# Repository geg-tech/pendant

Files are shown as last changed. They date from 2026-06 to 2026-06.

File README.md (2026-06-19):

# pendant
my #pendant submission for hack club! based off the arcane potion from defend the statue np <br/>
> "wtf is defend the statue" you may ask <br/>
> its a roblox game! its really fun! play it! play it! play it! [now!](https://www.roblox.com/games/6911596531/Defend-the-Statue)
> i have like 160 hours in ts

this keychain lights up in rgb colors and changes colors depending if you shake it or not, powered all by a seeed esp32! <br/>

## schematic
 <br/>
> enjoy dumbfounded soup <br/>

## pcb
 <br/>
 <br/>
 <br/>

## cad n case n stuff
 <br/>
 <br/>
 <br/>
 <br/>

## bom
find it [here](https://github.com/geg-tech/pendant/blob/main/pendant%20BOM%20-%20Sheet1.csv)! (or just go to the bom shaped .csv file in this repo right above ya)

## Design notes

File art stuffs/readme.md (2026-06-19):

# woah
all of the assets n thingies i used to make this! <br/>

## inspiration/links
wiki page for the item i recreated: [https://dtsnp.miraheze.org/wiki/Class_Potions#tabber-Arcane_Potion](https://dtsnp.miraheze.org/wiki/Class_Potions#tabber-Arcane_Potion)
> ^ this link might change in the future (the miraheze is a wip!) <br/>

game this is based off of: [https://www.roblox.com/games/6911596531/Defend-the-Statue](https://www.roblox.com/games/6911596531/Defend-the-Statue) <br/>
<br/>
 <br/>
<br/>
 <br/>

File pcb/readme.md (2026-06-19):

# pcb stuff
find the source files n stuff here + production <br/>
> its a 2 for 1 deal! <br/>

 <br/>
 <br/>

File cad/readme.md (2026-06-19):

# yeah welcome to the cad n case zone

what else am i supposed to put here <br/>
idk <br/>

 <br/>
> pcb is supposed to be purple too but kicad exported the soldermask as a bunch of uncolorable surfaces lol

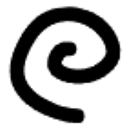
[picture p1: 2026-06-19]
art stuffs/swirl 2.png

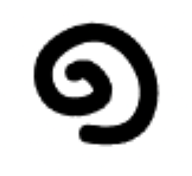
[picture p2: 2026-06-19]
art stuffs/swirl.png

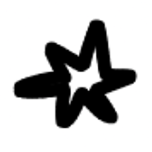
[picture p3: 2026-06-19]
art stuffs/boom.png

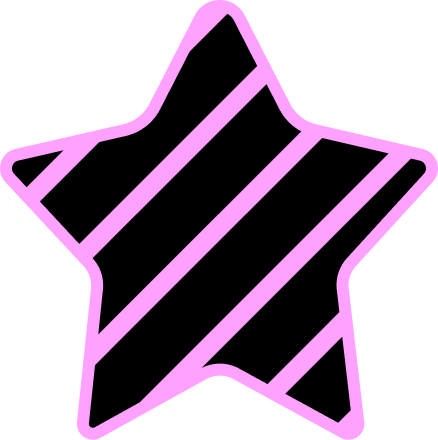
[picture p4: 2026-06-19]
art stuffs/filling star.png

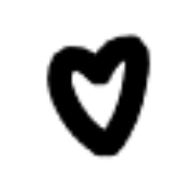
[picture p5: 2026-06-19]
art stuffs/heart.png

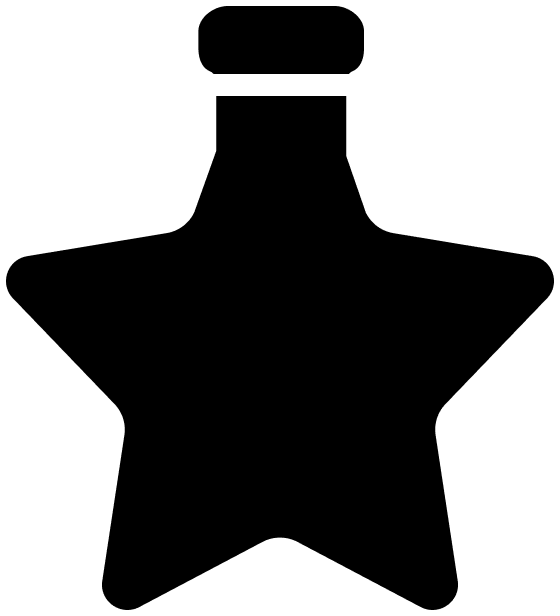
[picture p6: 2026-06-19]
art stuffs/outline.png

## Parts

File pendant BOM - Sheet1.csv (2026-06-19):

Name | Price | Purpose | Link
Seeed Studio XIAO ESP32-S3 | $4.60 | microcontroller | https://www.aliexpress.us/item/3256806801590776.html?curPageLogUid=GbnsKMYMMvNn
SK6812 Mini E | $2.42 | RGB LEDs that glow :D | https://www.aliexpress.us/item/3256805007401420.html?mp=1
MPU6050 | $2.88 (Already Owned) | gyroscope/accelerometer that senses motion/tilt | https://www.aliexpress.us/item/3256812014348809.html?curPageLogUid=7mJYeUUHuUoy
Slide Switch | $2.06 (Already Owned) | serves as a toggle for power | https://www.aliexpress.us/item/3256806975868130.html?curPageLogUid=15Y382B671XB
PCB | $5.30 | wires stuff together | JLCPCB
3.7V Battery | $5.44 | powers the thingy | https://www.aliexpress.us/item/3256808031709894.html?curPageLogUid=JW3njS3ESXuJ
3D printed case | $0 | holds the pcb in place and battery, look cool | printing myself
 | Subtotal: | $22.70
 | Actual subtotal (taking away items already owned): | $17.76
 | Actual Total (Shipping + tax): | $31.50

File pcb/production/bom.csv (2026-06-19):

Designator | Footprint | Quantity | Value | LCSC Part #
A1 | PinHeader_1x10_P2.54mm_Vertical | 1 | ~
D1, D10, D11, D12, D13, D14, D18, D2, D3, D4, D5, D6, D7, D9 | LED_SK6812MINI-E_3.2x2.8mm_P1.5mm_ReverseMount | 14 | SK6812MINI-E
SW1 | slideswitch | 1 | SW_SPDT
TP1 | TestPoint_Pad_D2.0mm | 1 | GND test Point
TP2 | TestPoint_Pad_D2.0mm | 1 | BAT Test Point
U1 | XIAO-ESP32S3-SMD | 1 | XIAO-ESP32-S3-SMD

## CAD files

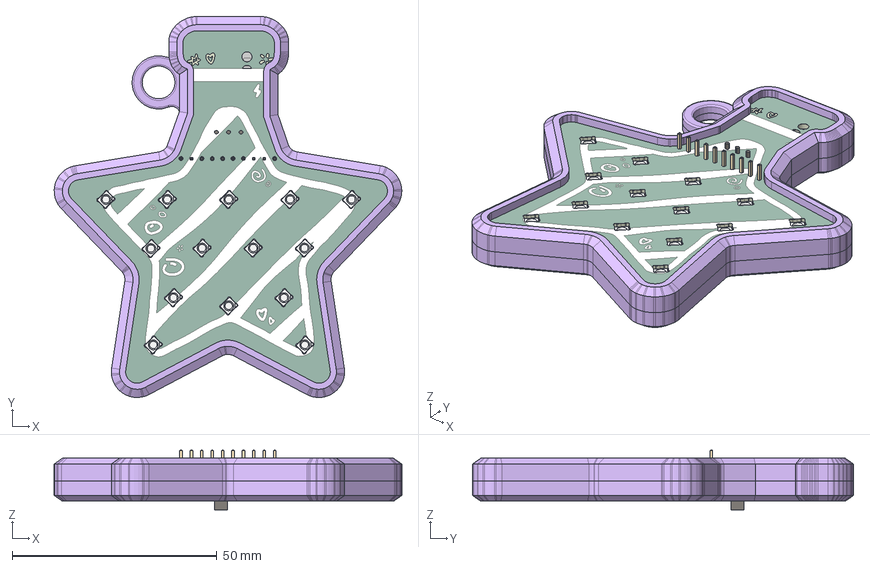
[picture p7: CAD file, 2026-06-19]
cad/pendant-assembly.step
84.9 x 93.1 x 14.6 mm
Pin1 x 14
Pin2 x 14
Pin3 x 14
Pin4 x 14
PinHeader_1x10_P2.54mm_Vertical
XIAO-ESP32S3 v2
pendant_silkscreen
pendant_silkscreen_1
pendant_soldermask
pendant_soldermask_1
pendant_PCB
mpu standin
bottom half
top half

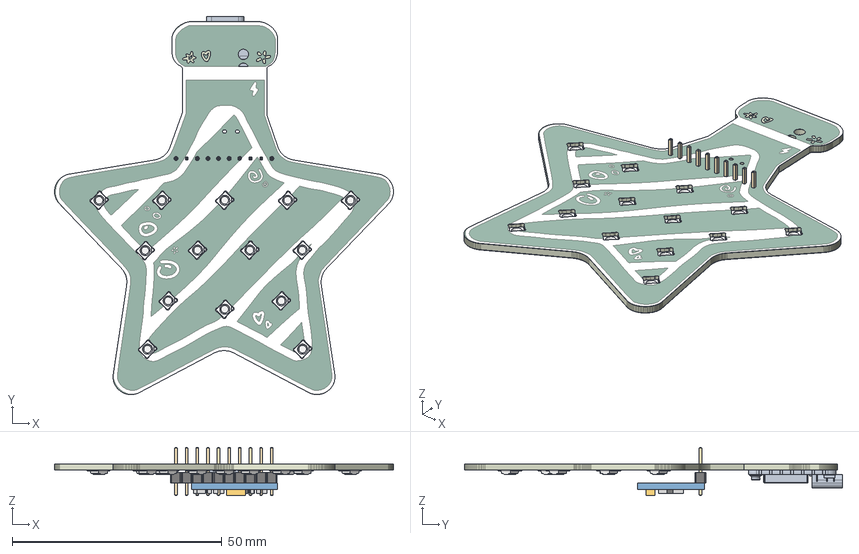
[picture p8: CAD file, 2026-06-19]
pcb/pendantbytfr.step
80.9 x 90.3 x 11.5 mm
Pin1 x 14
Pin2 x 14
Pin3 x 14
Pin4 x 14
PinHeader_1x10_P2.54mm_Vertical
pcb
XIAO-ESP32S3 v2
pendant_silkscreen x 2
pendant_soldermask x 2
pendant_PCB

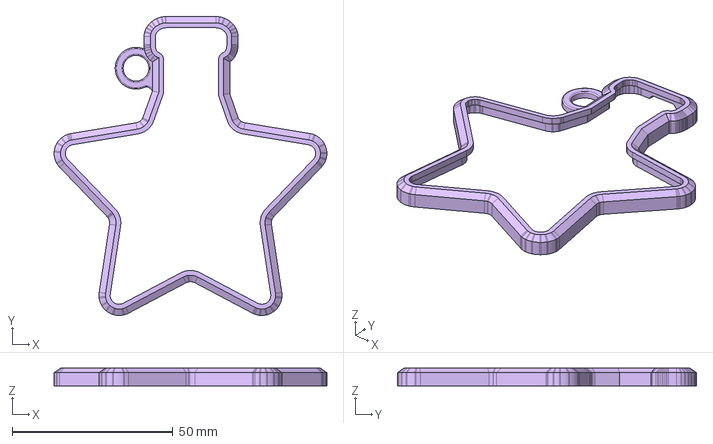
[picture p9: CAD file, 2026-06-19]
cad/top half.step
84.9 x 93.1 x 5.50 mm

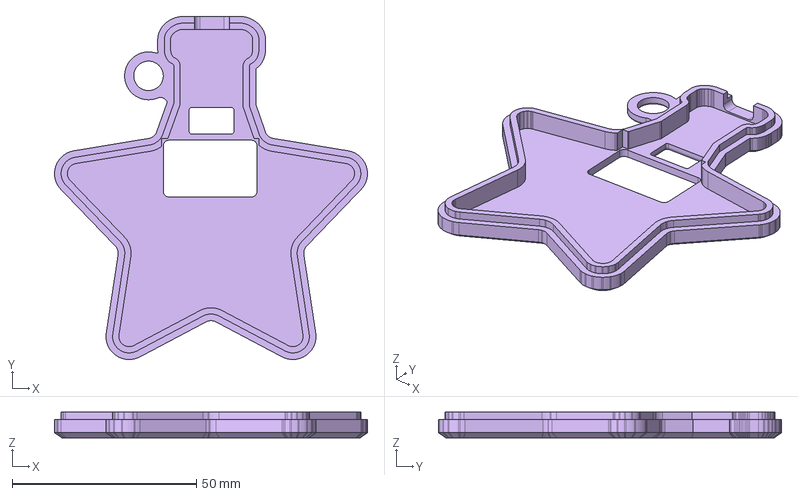
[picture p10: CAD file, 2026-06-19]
cad/bottom half.step
84.9 x 93.1 x 7.00 mm

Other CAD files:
cad/pendant-assembly.f3z

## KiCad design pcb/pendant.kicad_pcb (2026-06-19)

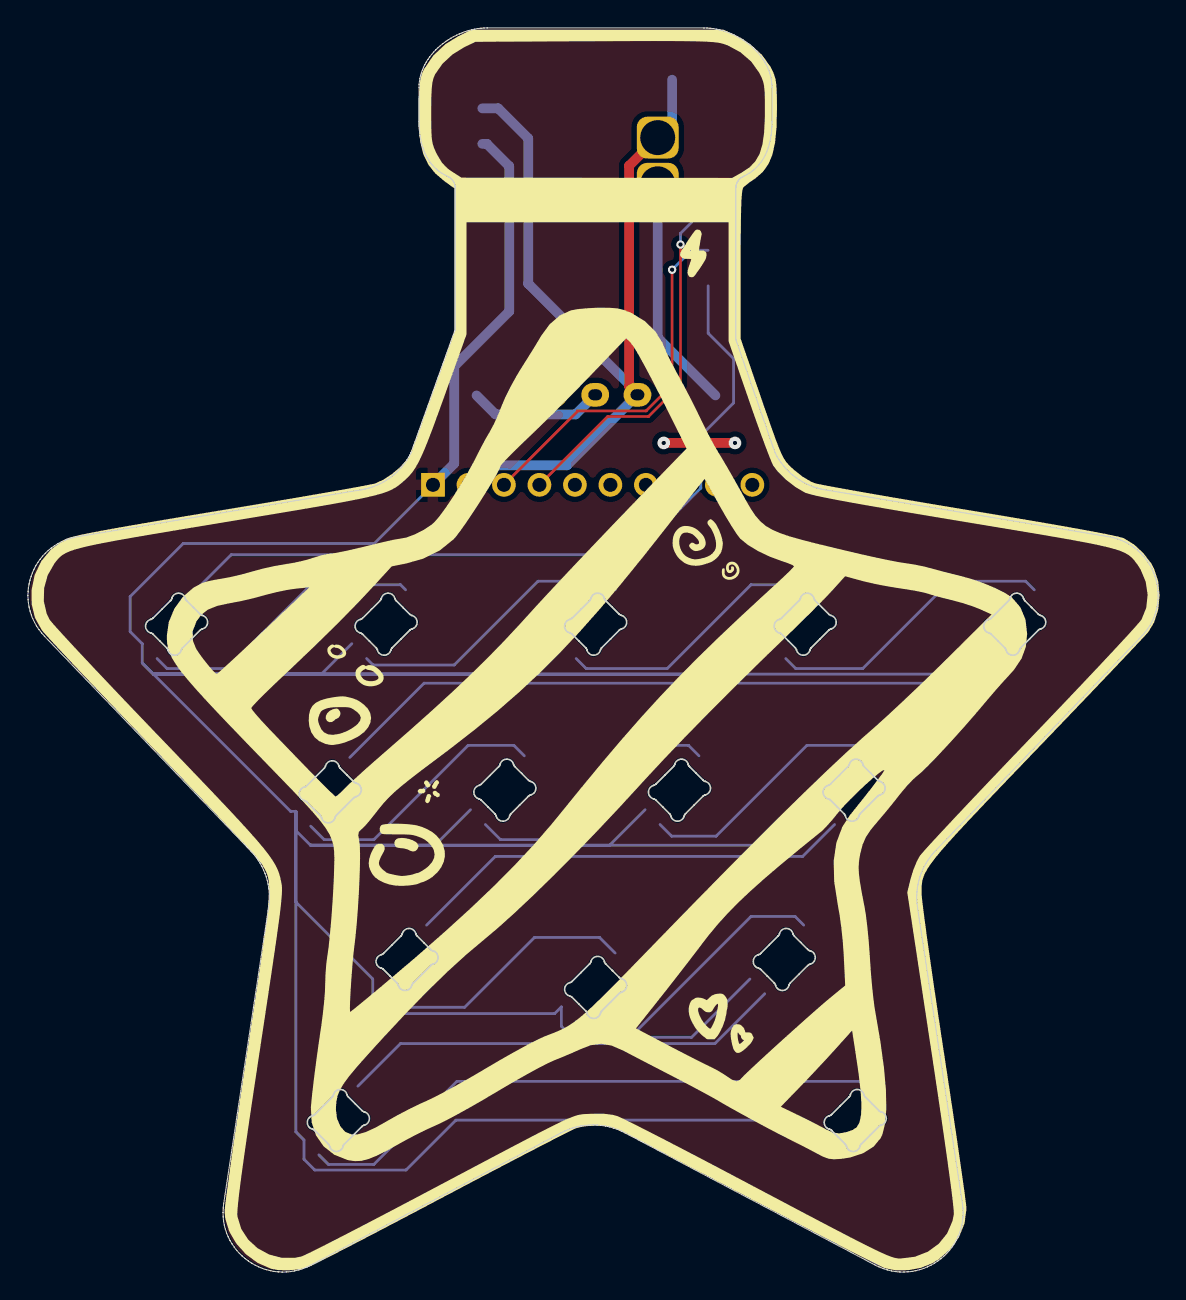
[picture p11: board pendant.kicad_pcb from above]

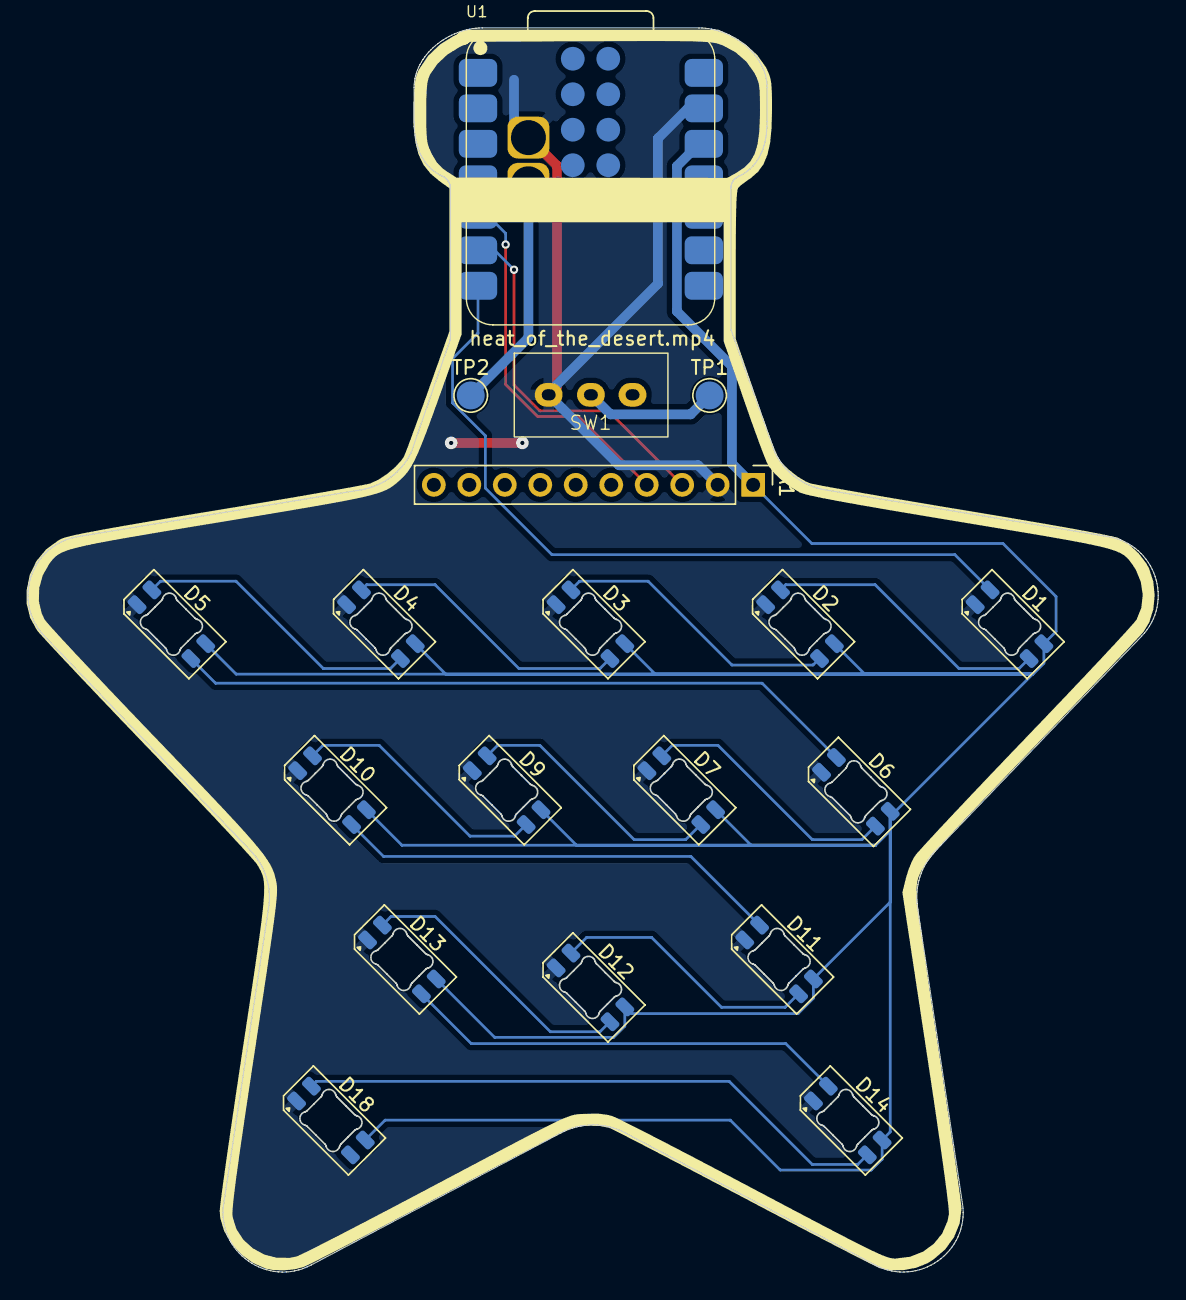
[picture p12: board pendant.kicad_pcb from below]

Board: 2 copper layers, 80.9 x 89.1 mm, 19 parts (19 on the bottom side), 20 nets.

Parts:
A1: PinHeader_1x10_P2.54mm_Vertical
D1, D2, D3, D4, D5, D6, D7, D9, D10, D11, D12, D13, D14, D18: SK6812MINI-E; LED_SK6812MINI-E_3.2x2.8mm_P1.5mm_ReverseMount
SW1: SW_SPDT; slideswitch
TP1: GND test Point; TestPoint_Pad_D2.0mm
TP2: BAT Test Point; TestPoint_Pad_D2.0mm
U1: XIAO-ESP32-S3-SMD; XIAO-ESP32S3-SMD

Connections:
+3V3: A1.1, D1.3 (VDD), D2.3 (VDD), D3.3 (VDD), D4.3 (VDD), D5.3 (VDD), D6.3 (VDD), D7.3 (VDD), D9.3 (VDD), D10.3 (VDD), D11.3 (VDD), D12.3 (VDD), D13.3 (VDD), D14.3 (VDD), D18.3 (VDD), U1.12 (3V3)
GND: A1.2, D1.1 (VSS), D2.1 (VSS), D3.1 (VSS), D4.1 (VSS), D5.1 (VSS), D6.1 (VSS), D7.1 (VSS), D9.1 (VSS), D10.1 (VSS), D11.1 (VSS), D12.1 (VSS), D13.1 (VSS), D14.1 (VSS), D18.1 (VSS), SW1.1 (A), U1.13 (GND), U1.16 (GND)
LED: D1.2 (DIN), U1.7 (GPIO43_A6_D6_TX)
unnamed: D1.4 (DOUT), D2.2 (DIN)
unnamed: D2.4 (DOUT), D3.2 (DIN)
unnamed: D3.4 (DOUT), D4.2 (DIN)
unnamed: D4.4 (DOUT), D5.2 (DIN)
unnamed: D5.4 (DOUT), D6.2 (DIN)
unnamed: D6.4 (DOUT), D7.2 (DIN)
unnamed: D7.4 (DOUT), D9.2 (DIN)
unnamed: D9.4 (DOUT), D10.2 (DIN)
unnamed: D10.4 (DOUT), D11.2 (DIN)
unnamed: D11.4 (DOUT), D12.2 (DIN)
unnamed: D12.4 (DOUT), D13.2 (DIN)
unnamed: D13.4 (DOUT), D14.2 (DIN)
unnamed: D14.4 (DOUT), D18.2 (DIN)
unnamed: SW1.1 (A), TP1.1 (1_1)
SCL: A1.3, U1.6 (GPIO6_A5_D5_SCL)
SDA: A1.4, U1.5 (GPIO5_A4_D4_SDA)
VBAT: TP2.1 (1_1), U1.15 (BAT)

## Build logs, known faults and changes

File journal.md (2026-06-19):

# la journale
>  17 38. ay. <br/>

this is the journal for my pendant submission! projects are due tomorrow so dev logs are gonna b pretty packed <br/>
* my submission is based on the [Arcane Potion](https://official-defend-the-statue.fandom.com/wiki/Class_Potions#Arcane_Potion) from [Defend The Statue: Nostalgic Proctors](https://www.roblox.com/games/6911596531/Defend-the-Statue), a roblox game i have way too much hours in lmao

### started: 6/17/26
### finished design: 6/18/26
### total hours (as of submission): ~8.6 hours

## 6/17/26 - comin up with ideas, drawing outlines
today i came up with some ideas for pendant <br/>
there's not that much criteria for pendant other than making it look pretty and being under 4 inches, so i started comin up with some ideas: <br/>
 <br/>
in the end i decided to do the fluid simulation idea with the arcane potion <br/>
* i feel like doing a fluid simulation with a more unusual shape like the star would be interesting + defend the statue was and is still now one of my fav games on roblox <br/>
* i also wanna experiment with different pcb colors other than my usual black and white silkscreen

after getting my idea sorted, i started work on my outline
* i chose figma to do this since ion really know any other vector drawing software other than like illustrator (in which my school booted my license) <br/>
 <br/>
the corners of the star are supposed to be sharper tbh but im planning to make the case for it wrap and sandwich the pcb around it so

### hours spent: 0.8 hours

## 6/18/26 (part 1) - coming up with general layout, schematic work
i should've came up with my layout before making my layout but whatever <br/>
anyways back to the excalidraw mines <br/>
 <br/>
thankfully i have a bunch of mpu6050 sensors from a project i planned to do but never did so i dont have to order those <br/>
after that, i went onto kicad to make my schematic <br/>

* i initially wanted to recreate an led matrix for my pendant, but after digging around and finding the [adafruit schematic for their neopixel matrix](https://github.com/adafruit/Adafruit-NeoPixel-8x8-Matrix/blob/master/Adafruit_NeoMatrix_8x8%20v2.sch), i realized that its quite literally just the same type of config i've been using for my rgb lights but with extra capacitors and a resistor lmao <br/>
* i also tossed in a slide power switch so that i dont burn all of my battery when i permanently solder my board together. i initially thought i was gonna have to buy new slide switches, but i found one lying around in my stash of electronic parts
* i wired up the accelerometer according to this [handy article](https://lastminuteengineers.com/mpu6050-accel-gyro-arduino-tutorial/#mpu6050-module-pinout) by last minute engineers (idk what else to say)

### hours spent: 1.9 hours

## 6/18/26 (part 2) - pcb design!!!
ok its slightly too big :peefest: <br/>
for the most part i followed the usual footprints, only having to make a custom footprint for my slide switch with some calipers since the pins on the switch are just a tiny bit too big for the usual pin header connector footprints <br/>
however when importing my svg into kicad, i measured the height of the board to be around 110mm, or just bigger than 4 inches <br/>
 <br/>
which meant: <br/>
### REDESIGN TIME!!!!!!!!!!!!
> (and by redesign i just lowered the neck of the potion and made it a tinge wider so i dont have to scale it as much
 <br/>
yeah sure its not game accurate anymore but womp womp id rather have the cool ass lanyard and keychain <br/>

after getting that sorted (its now 3.5 inches ish), i placed down my components
* i took inspiration from the split keeb tutorial on blueprint, specifically copying the xiao footprint in their repo for mine since the footprint that came with mine didn't have the holes to solder the battery pads
* after that, i arranged my leds in the star pattern of my outline. i angled the leds to 45 degrees for aesthetics, making sure to space them out roughly evenly <br/>
 <br/>
* the front part is what will be shown in the final product, so i'll have most of my decorative and pretty drawings on there, while the back is gonna be covered up (so memes n shitposts)
* its also why most of my components are on the back <br/>
after getting my layout, i started routing <br/>
* again, i used the track widths found in the split keeb tutorial to guide my routing for the battery/power system since its pretty much identical other than the microcontroller
* this was also where i found out you could change the board requirements in kicad to dodge drc errors (i had like 56 of them due to the led footprints lol) <br/>


## hours spent: 2-ish hours

## 6/18/26 (part 3) - ART!!!!!!!!!!!!!!!!
now that i had the annoyin circuit stuff out of the way, i could focus on making the pcb look pretty :D <br/>
* i started off with the outline i had in figma, creating an inner outline to make a simple border around the pcb
* after that, i recreated the neon purple inside of the potion by creating a rounded star. to replicate the "color", i used a diagonal line shading thing which was made by using the pattern fill option with a square with diagonal lines in it <br/>
 <br/>
* the filling looked a little *too* clean and straight in a sense, so i went back and purposefuly made the filling look more wavy and handrawn, which i feel improved the vibe of the pcb a ton
* after that, i started work on smaller decor, starting off my drawing some small doodles in kleki and importing them into figma so i could resize them for kicad <br/>
 <br/>
i aimed for magical-themed doodles (waves, lightning, swirls, etc.) and tossed them into my pcb <br/>
> this was also where i found out that kleki had a smoothening option! made drawing on trackpad 10000000 times easier :3 <br/>

 <br/>
the 3d models for the components were fairly easy to get tbh. the only issue i had was not finding the specific MPU6050 i had which had 10 pins, so i decided to just settle on an 8 pin model and call it there lol <br/>
 <br/>

## hours spent: 1.4 hours

## 6/18/26 (part 4) - cad and finishing!!!
woah mama its like 23 minutes until the due date (i'll make this quick)<br/>
after i got my pcb done and decorated, i dragged fusion out of its dusty bed and worked on the cad <br/>
* my plan for the case was fairly simple: make an enclosure encasing the back but exposing the front of the pcb
* i considered making a cover for the front to diffuse the light, but im highkey running out of time lmao

it was a bit of a pain to do projections and outlines of the pcb in cad due to the custom outline in figma translating into kicad, then fusion (and thus resulting in an edge that had like a million arcs and segments), but we lowk got there <br/>
 <br/>
in an attempt to stay true to the source material, i made the case a light lavender-ish purple, as well as making a slightly thicker hole to hook onto the lanyard <br/>
 <br/>
i designed my case so that the halves should press fit into each other securely with the lanyard providing support through the ring, but a light amount of glue also works ig (yuck glue) <br/>
 <br/>

after that, i went to the repo and uploaded all of my stuff. for the firmware, i'm using the code from [this post from digikey](https://www.digikey.com/en/maker/projects/esp32-fluid-simulation-on-16x16-led-matrix/9c5a42f7ecfd43d9bc7689b2e9a5113f) about their fluid simulation, through slightly tweaked to not leave in the color select button and to use my pinout.
* yeah its kinda cheaty, but at the same time most of the components are similiar + wip firmware

hours spent: 2.5-ish hours

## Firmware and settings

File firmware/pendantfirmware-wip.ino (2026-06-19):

 // colors:   0 = Red, 32 = Orange, 64 = Yellow, 96 = Green, 128 = Aqua, 160 = Blue, 192 = Purple, 224 = Pink


#include <FastLED.h>
#include <Wire.h>
#include <MPU6050.h>

// Pin definitions
#define LED_PIN     5
#define SDA_PIN     21
#define SCL_PIN     22

#define NUM_LEDS    256
#define MATRIX_WIDTH 16
#define MATRIX_HEIGHT 16
#define FLUID_PARTICLES 64  //80/64
#define BRIGHTNESS  30
#define NUM_COLORS  3   // Number of color options

// Structures
struct Vector2D {
    float x;
    float y;
};

struct Particle {
    Vector2D position;
    Vector2D velocity;
};

// Global variables
CRGB leds[NUM_LEDS];
MPU6050 mpu;
Particle particles[FLUID_PARTICLES];
Vector2D acceleration = {0, 0};

// Color switching variables
uint8_t currentColorIndex = 0;
unsigned long lastDebounceTime = 0;
const unsigned long debounceDelay = 200;

// Define the colors (you can change these hue values)
const uint8_t COLORS[NUM_COLORS] = {
    160,  // Blue
    0,    // Red
    96    // Green
};

// Mutex for synchronization
portMUX_TYPE dataMux = portMUX_INITIALIZER_UNLOCKED;

// Constants for physics
const float GRAVITY = 0.08f;  //0.3f /098f
const float DAMPING = 0.92f;   //0.99f /0.9f
const float MAX_VELOCITY = 0.6f; //0.6f /2.9f

// Function prototypes
void initMPU6050();
void initLEDs();
void initParticles();
void updateParticles();
void drawParticles();
void MPUTask(void *parameter);
void LEDTask(void *parameter);
void checkButton();

// Function to convert x,y coordinates to LED index
int xy(int x, int y) {
    x = constrain(x, 0, MATRIX_WIDTH - 1);
    y = constrain(y, 0, MATRIX_HEIGHT - 1);
    return (y & 1) ? (y * MATRIX_WIDTH + (MATRIX_WIDTH - 1 - x)) : (y * MATRIX_WIDTH + x);
}

void checkButton() {
    static bool lastButtonState = HIGH;
    bool buttonState = digitalRead(BUTTON_PIN);

    if (buttonState == LOW && lastButtonState == HIGH) {  // Button pressed
        if ((millis() - lastDebounceTime) > debounceDelay) {
            currentColorIndex = (currentColorIndex + 1) % NUM_COLORS;
            lastDebounceTime = millis();
        }
    }
    lastButtonState = buttonState;
}

void drawParticles() {
    FastLED.clear();
    
    bool occupied[MATRIX_WIDTH][MATRIX_HEIGHT] = {{false}};
    
    struct ParticleIndex {
        int index;
        float position;
    };
    
    ParticleIndex sortedParticles[FLUID_PARTICLES];
    for (int i = 0; i < FLUID_PARTICLES; i++) {
        sortedParticles[i].index = i;
        sortedParticles[i].position = particles[i].position.y * MATRIX_WIDTH + particles[i].position.x;
    }
    
    for (int i = 0; i < FLUID_PARTICLES - 1; i++) {
        for (int j = 0; j < FLUID_PARTICLES - i - 1; j++) {
            if (sortedParticles[j].position > sortedParticles[j + 1].position) {
                ParticleIndex temp = sortedParticles[j];
                sortedParticles[j] = sortedParticles[j + 1];
                sortedParticles[j + 1] = temp;
            }
        }
    }

    for (int i = 0; i < FLUID_PARTICLES; i++) {
        int particleIndex = sortedParticles[i].index;
        int x = round(particles[particleIndex].position.x);
        int y = round(particles[particleIndex].position.y);
        
        x = constrain(x, 0, MATRIX_WIDTH - 1);
        y = constrain(y, 0, MATRIX_HEIGHT - 1);
        
        if (!occupied[x][y]) {
            int index = xy(x, y);
            if (index >= 0 && index < NUM_LEDS) {
                float speed = sqrt(
                    particles[particleIndex].velocity.x * particles[particleIndex].velocity.x + 
                    particles[particleIndex].velocity.y * particles[particleIndex].velocity.y
                );
                
                uint8_t hue = COLORS[currentColorIndex];
                uint8_t sat = 255;
                uint8_t val = constrain(180 + (speed * 50), 180, 255);
                
                leds[index] = CHSV(hue, sat, val);
                occupied[x][y] = true;
            }
        } else {
            for (int r = 1; r < 3; r++) {
                for (int dx = -r; dx <= r; dx++) {
                    for (int dy = -r; dy <= r; dy++) {
                        if (abs(dx) + abs(dy) == r) {
                            int newX = x + dx;
                            int newY = y + dy;
                            if (newX >= 0 && newX < MATRIX_WIDTH && 
                                newY >= 0 && newY < MATRIX_HEIGHT && 
                                !occupied[newX][newY]) {
                                int index = xy(newX, newY);
                                if (index >= 0 && index < NUM_LEDS) {
                                    leds[index] = CHSV(COLORS[currentColorIndex], 255, 180);
                                    occupied[newX][newY] = true;
                                    goto nextParticle;
                                }
                            }
                        }
                    }
                }
            }
            nextParticle:
            continue;
        }
    }
    
    FastLED.show();
}

void updateParticles() {
    Vector2D currentAccel;
    portENTER_CRITICAL(&dataMux);
    currentAccel = acceleration;
    portEXIT_CRITICAL(&dataMux);

    currentAccel.x *= 0.3f;
    currentAccel.y *= 0.3f;

    for (int i = 0; i < FLUID_PARTICLES; i++) {
        particles[i].velocity.x = particles[i].velocity.x * 0.9f + (currentAccel.x * GRAVITY);
        particles[i].velocity.y = particles[i].velocity.y * 0.9f + (currentAccel.y * GRAVITY);

        particles[i].velocity.x = constrain(particles[i].velocity.x, -MAX_VELOCITY, MAX_VELOCITY);
        particles[i].velocity.y = constrain(particles[i].velocity.y, -MAX_VELOCITY, MAX_VELOCITY);

        float newX = particles[i].position.x + particles[i].velocity.x;
        float newY = particles[i].position.y + particles[i].velocity.y;

        if (newX < 0.0f) {
            newX = 0.0f;
            particles[i].velocity.x = fabs(particles[i].velocity.x) * DAMPING;
        } 
        else if (newX >= (MATRIX_WIDTH - 1)) {
            newX = MATRIX_WIDTH - 1;
            particles[i].velocity.x = -fabs(particles[i].velocity.x) * DAMPING;
        }

        if (newY < 0.0f) {
            newY = 0.0f;
            particles[i].velocity.y = fabs(particles[i].velocity.y) * DAMPING;
        } 
        else if (newY >= (MATRIX_HEIGHT - 1)) {
            newY = MATRIX_HEIGHT - 1;
            particles[i].velocity.y = -fabs(particles[i].velocity.y) * DAMPING;
        }

        particles[i].position.x = constrain(newX, 0.0f, MATRIX_WIDTH - 1);
        particles[i].position.y = constrain(newY, 0.0f, MATRIX_HEIGHT - 1);

        particles[i].velocity.x *= 0.95f;
        particles[i].velocity.y *= 0.95f;
    }

    for (int i = 0; i < FLUID_PARTICLES; i++) {
        for (int j = i + 1; j < FLUID_PARTICLES; j++) {
            float dx = particles[j].position.x - particles[i].position.x;
            float dy = particles[j].position.y - particles[i].position.y;
            float distanceSquared = dx * dx + dy * dy;

            if (distanceSquared < 1.0f) {
                float distance = sqrt(distanceSquared);
                float angle = atan2(dy, dx);
                
                float repulsionX = cos(angle) * 0.5f;
                float repulsionY = sin(angle) * 0.5f;

                particles[i].position.x -= repulsionX * 0.3f;
                particles[i].position.y -= repulsionY * 0.3f;
                particles[j].position.x += repulsionX * 0.3f;
                particles[j].position.y += repulsionY * 0.3f;

                Vector2D avgVel = {
                    (particles[i].velocity.x + particles[j].velocity.x) * 0.5f,
                    (particles[i].velocity.y + particles[j].velocity.y) * 0.5f
                };

                particles[i].velocity = avgVel;
                particles[j].velocity = avgVel;
            }
        }
    }
}

void initMPU6050() {
    Serial.println("Initializing MPU6050...");
    mpu.initialize();
    
    if (!mpu.testConnection()) {
        Serial.println("MPU6050 connection failed!");
        while (1) {
            delay(100);
        }
    }
    
    mpu.setFullScaleAccelRange(MPU6050_ACCEL_FS_2);
    Serial.println("MPU6050 initialized");
}

void initLEDs() {
    Serial.println("Initializing LEDs...");
    FastLED.addLeds<WS2812B, LED_PIN, GRB>(leds, NUM_LEDS);
    FastLED.setBrightness(BRIGHTNESS);
    FastLED.clear(true);
    Serial.println("LEDs initialized");
}

void initParticles() {
    Serial.println("Initializing particles...");
    int index = 0;
    
    for (int y = MATRIX_HEIGHT - 4; y < MATRIX_HEIGHT; y++) {
        for (int x = 0; x < MATRIX_WIDTH && index < FLUID_PARTICLES; x++) {
            particles[index].position = {static_cast<float>(x), static_cast<float>(y)};
            particles[index].velocity = {0.0f, 0.0f};
            index++;
        }
    }
    
    Serial.printf("Total particles initialized: %d\n", index);
}

void MPUTask(void *parameter) {
    while (true) {
        int16_t ax, ay, az;
        mpu.getAcceleration(&ax, &ay, &az);
        
        portENTER_CRITICAL(&dataMux);
        acceleration.x = -constrain(ax / 16384.0f, -1.0f, 1.0f);
        acceleration.y = constrain(ay / 16384.0f, -1.0f, 1.0f);
        portEXIT_CRITICAL(&dataMux);
        
        vTaskDelay(pdMS_TO_TICKS(10));
    }
}

void LEDTask(void *parameter) {
    TickType_t xLastWakeTime = xTaskGetTickCount();
    const TickType_t xFrequency = pdMS_TO_TICKS(16);
    
    while (true) {
        checkButton();
        updateParticles();
        drawParticles();
        vTaskDelayUntil(&xLastWakeTime, xFrequency);
    }
}

void setup() {
    Serial.begin(115200);
    delay(1000);
    Serial.println("Starting initialization...");

    // Initialize button pin
    pinMode(BUTTON_PIN, INPUT_PULLUP);

    Wire.begin(SDA_PIN, SCL_PIN);
    Wire.setClock(400000);

    initMPU6050();
    initLEDs();
    initParticles();

    xTaskCreatePinnedToCore(
        MPUTask,
        "MPUTask",
        4096,
        NULL,
        2,
        NULL,
        0
    );

    xTaskCreatePinnedToCore(
        LEDTask,
        "LEDTask",
        4096,
        NULL,
        1,
        NULL,
        1
    );

    Serial.println("Setup complete");
}

void loop() {
    vTaskDelete(NULL);
}
